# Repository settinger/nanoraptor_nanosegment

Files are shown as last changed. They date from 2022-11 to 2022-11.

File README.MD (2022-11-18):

# The NanoRaptor NanoSegment

## Experiments in miniature 7-segment displays

### Sam Ettinger, November 2022

Like many good projects, this started with [a prank tweet:](https://twitter.com/NanoRaptor/status/1483962337334022145)

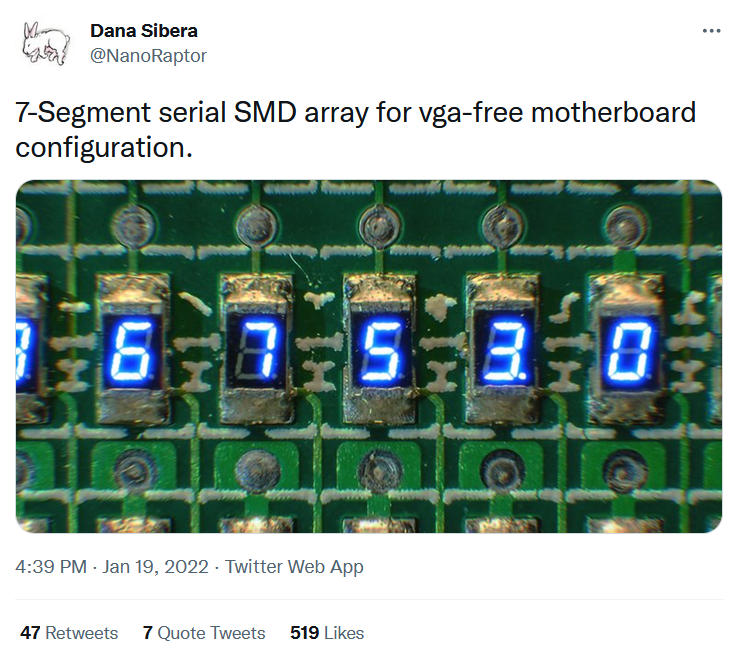
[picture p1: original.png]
A screenshot of a tweet showing surface mount resistors that have been photoshopped to look like they have 7-segment displays on them. The tweet text says "7-Segment serial SMD array for vga-free motherboard configuration."


Like many others, I immediately got sucked into hypotheticals, wondering what it would take to make one of these IRL. Some 0201-sized LEDs in a 7-segment arrangement could fit in an 0805-ish footprint, right?

There are three KiCad projects in the `kicad/` folder:
- `6pin_7seg_0806`, the first version. It's just a panelized PCB with no schematic and some, shall we say, unique features (TODO: explain)
- `6pin_7seg_0806_display_board`. Once the 6-pin 0806 modules are assembled, the modules can be soldered to this board and controlled with an ATtiny84. There are some unused 0805 footprints nearby the modules, which I thought would contribute to it looking like a "real" component.
- `nanoraptor_nanosegment`, my current idea. I want to see if I can fold up an OSH Park flex PCB into a 1208-size footprint with just two pins, like in the original tweet.

TODO: finish this

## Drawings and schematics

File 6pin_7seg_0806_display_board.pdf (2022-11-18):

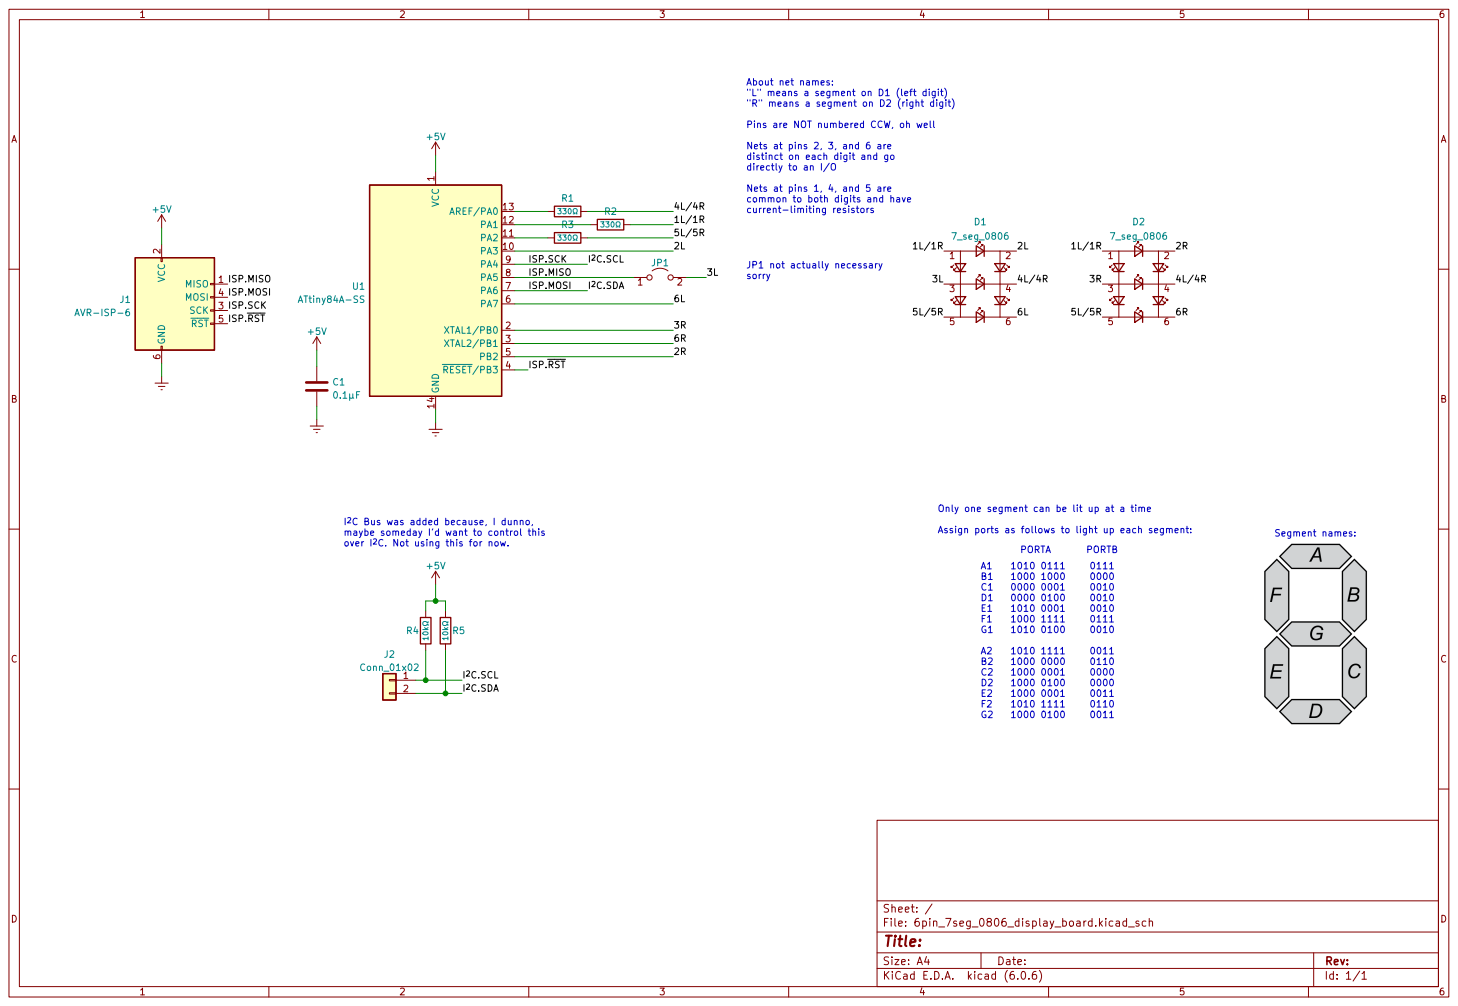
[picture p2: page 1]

About net names: "L" means a segment on D1 (left digit)

"R" means a segment on D2 (right digit) Pins are NOT numbered CCW, oh well Nets at pins 2, 3, and 6 are

distinct on each digit and go
directly to an I/O

1 PA3 10 PA2 11 PA1 12 AREF/PA0 13 GND 14 XTAL1/PB0 2 XTAL2/PB1 3 ~{RESET}/PB3 4 PB2 5 PA7 6 PA6 7 PA5 8 PA4 9 U1 ATtiny84A-SS

Nets at pins 1, 4, and 5 are
common to both digits and have

2 SCK 3 MOSI 4 ~{RST} 5 GND

0011 A1B1C1 D1E1F1G1 A2B2C2 D2E2F2G2 Only one segment can be lit up at a time

I^{2}C Bus was added because, I dunno,
maybe someday I'd want to control this
over I^{2}C. Not using this for now.

Assign ports as follows to light up each segment:

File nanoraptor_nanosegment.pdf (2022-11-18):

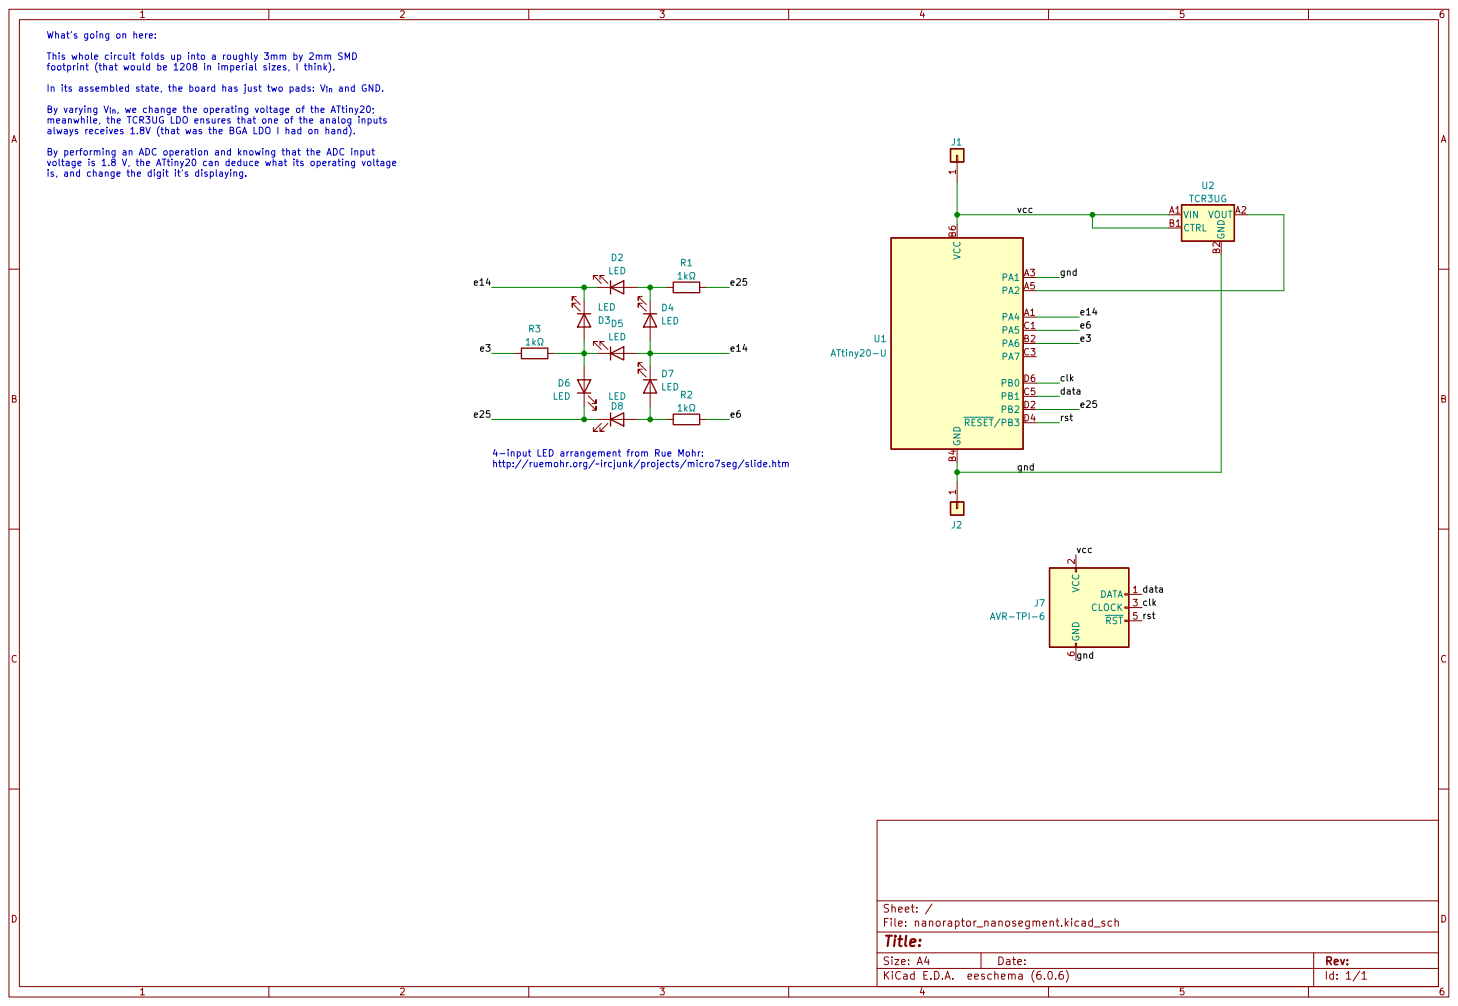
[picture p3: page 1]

This whole circuit folds up into a roughly 3mm by 2mm SMD
footprint (that would be 1208 in imperial sizes, I think).

In its assembled state, the board has just two pads: V_{in} and GND.

By varying V_{in}, we change the operating voltage of the ATtiny20;
meanwhile, the TCR3UG LDO ensures that one of the analog inputs
always receives 1.8V (that was the BGA LDO I had on hand).

By performing an ADC operation and knowing that the ADC input
voltage is 1.8 V, the ATtiny20 can deduce what its operating voltage
is, and change the digit it's displaying.

4-input LED arrangement from Rue Mohr:
http://ruemohr.org/~ircjunk/projects/micro7seg/slide.htm

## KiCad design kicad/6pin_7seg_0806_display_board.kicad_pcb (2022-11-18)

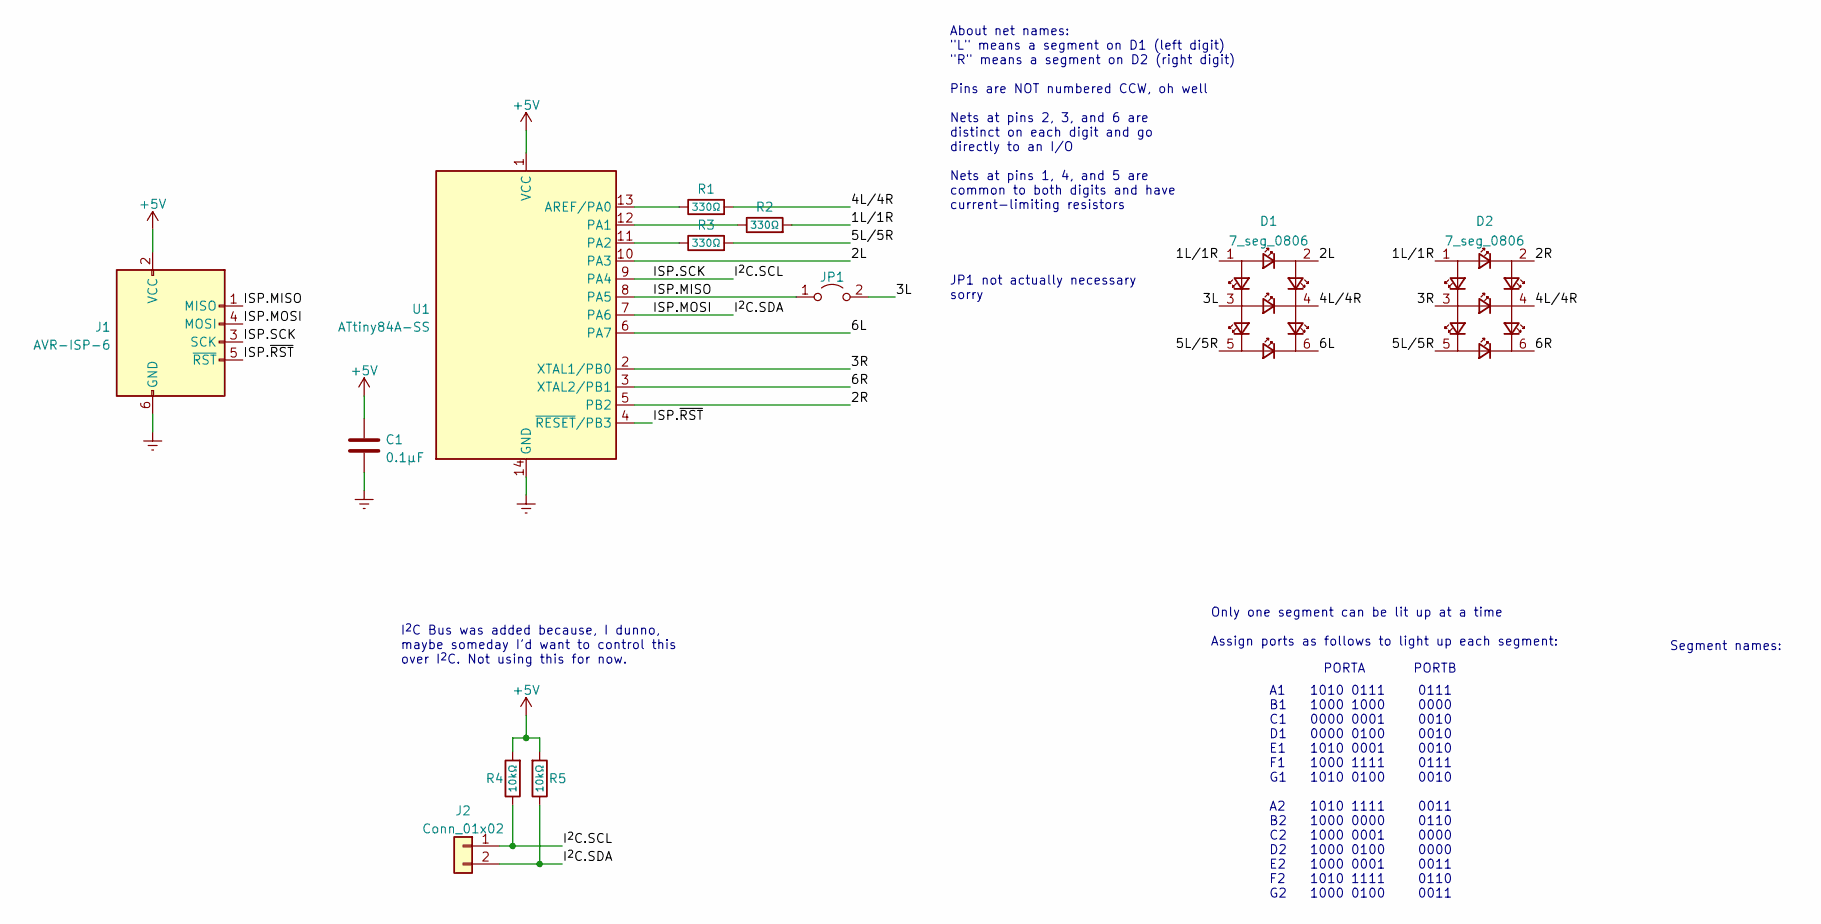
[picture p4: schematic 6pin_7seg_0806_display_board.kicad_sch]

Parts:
C1: 0.1μF; C_0805_2012Metric
D1, D2: 7_seg_0806; 7seg_land_pattern
J1: AVR-ISP-6; IDC_header_2x03_P2.54mm_edge-mount
J2: Conn_01x02; PinSocket_1x02_P2.54mm_Vertical
JP1: Jumper_2_Open; SolderJumper-2_P1.3mm_Open_RoundedPad1.0x1.5mm
R1, R2, R3: 330Ω; R_0805_2012Metric
R4, R5: 10kΩ; R_0805_2012Metric
U1: ATtiny84A-SS; SOIC-14_3.9x8.7mm_P1.27mm

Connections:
+5V: C1.1, J1.2 (VCC), R4.2, R5.2, U1.1 (VCC)
/1L/1R: D1.1 (A+F+), D2.1 (A+F+), R2.2
/2L: D1.2 (A-B+), U1.10 (PA3)
/2R: D2.2 (A-B+), U1.5 (PB2)
/3L: D1.3 (E+F-G+), JP1.2 (B)
/3R: D2.3 (E+F-G+), U1.2 (XTAL1/PB0)
/4L/4R: D1.4 (B-C+G-), D2.4 (B-C+G-), R1.2
/5L/5R: D1.5 (D+E-), D2.5 (D+E-), R3.2
/6L: D1.6 (C-D-), U1.6 (PA7)
/6R: D2.6 (C-D-), U1.3 (XTAL2/PB1)
/ISP.MISO: J1.1 (MISO), JP1.1 (A), U1.8 (PA5)
/ISP.MOSI: J1.4 (MOSI), J2.2, R5.1, U1.7 (PA6)
/ISP.SCK: J1.3 (SCK), J2.1, R4.1, U1.9 (PA4)
/ISP.~RST: J1.5 (~RST), U1.4 (~RESET/PB3)
GNDREF: C1.2, J1.6 (GND), U1.14 (GND)
unnamed: R1.1, U1.13 (AREF/PA0)
unnamed: R2.1, U1.12 (PA1)
unnamed: R3.1, U1.11 (PA2)

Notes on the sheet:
1010 0111 1000 1000 0000 0001 0000 0100 1010 0001 1000 1111 1010 0100 1010 1111 1000 0000 1000 0001 1000 0100 1000 0001 1010 1111 1000 0100
JP1 not actually necessary sorry
About net names: "L" means a segment on D1 (left digit) "R" means a segment on D2 (right digit) Pins are NOT numbered CCW, oh well Nets at pins 2, 3, and 6 are distinct on each digit and go directly to an I/O Nets at pins 1, 4, and 5 are common to both digits and have current-limiting resistors
A1 B1 C1 D1 E1 F1 G1 A2 B2 C2 D2 E2 F2 G2
0111 0000 0010 0010 0010 0111 0010 0011 0110 0000 0000 0011 0110 0011
I^{2}C Bus was added because, I dunno, maybe someday I'd want to control this over I^{2}C. Not using this for now.
Only one segment can be lit up at a time Assign ports as follows to light up each segment:
Segment names:
PORTA PORTB

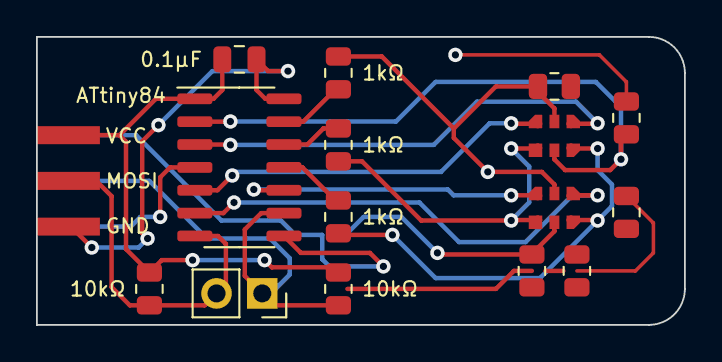
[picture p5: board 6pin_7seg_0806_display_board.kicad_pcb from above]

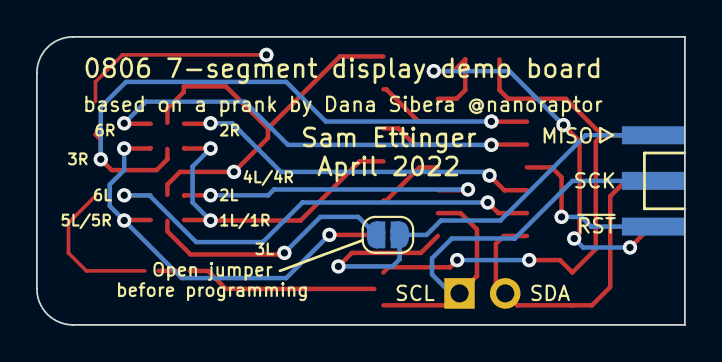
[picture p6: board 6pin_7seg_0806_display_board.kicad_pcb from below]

Board: 2 copper layers, 36.0 x 16.0 mm, 12 parts (2 on the bottom side), 18 nets.

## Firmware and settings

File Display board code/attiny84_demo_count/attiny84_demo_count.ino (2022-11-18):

// ATtiny84 setup for driving those tiny 7-segment surface mount dinguses
// THIS IS NOT GOOD CODE I WAS HUNGOVER AND DOING THIS IN THE MIDDLE OF A CON

#define PIN_1L  1  // Pin 1 of module L is connected to PA1 of the ATtiny84 (denoted "1" in ATtinyCore)
#define PIN_1R PIN_1L
#define PIN_2L  3  // Pin 2 module L: PA3 (attinycore 3)
#define PIN_2R  8  // Pin 2 module R: PB2 (attinycore 8)
#define PIN_3L  5  // Pin 3 module L: PA5 (attinycore 5)
#define PIN_3R 10  // Pin 3 module R: PB0 (attinycore 10)
#define PIN_4L  0  // Pin 4 module L: PA0 (attinycore 0)
#define PIN_4R PIN_4L
#define PIN_5L  2  // Pin 5 module L: PA2 (attinycore 2)
#define PIN_5R PIN_5L
#define PIN_6L  7  // Pin 6 module L: PA7 (attinycore 7)
#define PIN_6R  9  // Pin 6 module R: PB1 (attinycore 9)

#define PORTA_OUTPUT_MASK 0b10101111
#define PORTB_OUTPUT_MASK 0b00000111

#define OFF 0b00000000

// Arrangement of PORTA and PORTB inputs to illuminate the left module's segments, one at a time
#define SEG_A_L_PA 0b10100111
#define SEG_B_L_PA 0b10001000
#define SEG_C_L_PA 0b00000001
#define SEG_D_L_PA 0b00000100
#define SEG_E_L_PA 0b10100001
#define SEG_F_L_PA 0b10001111
#define SEG_G_L_PA 0b10100100

#define SEG_A_L_PB 0b00000111
#define SEG_B_L_PB 0b00000010
#define SEG_C_L_PB 0b00000010
#define SEG_D_L_PB 0b00000010
#define SEG_E_L_PB 0b00000010
#define SEG_F_L_PB 0b00000111
#define SEG_G_L_PB 0b00000010

// Arrangement of PORTA and PORTB inputs to illuminate the right module's segments, one at a time
#define SEG_A_R_PA 0b10101111
#define SEG_B_R_PA 0b10000000
#define SEG_C_R_PA 0b10000001
#define SEG_D_R_PA 0b10000100
#define SEG_E_R_PA 0b10000001
#define SEG_F_R_PA 0b10101111
#define SEG_G_R_PA 0b10000100

#define SEG_A_R_PB 0b00000011
#define SEG_B_R_PB 0b00000110
#define SEG_C_R_PB 0b00000000
#define SEG_D_R_PB 0b00000000
#define SEG_E_R_PB 0b00000011
#define SEG_F_R_PB 0b00000110
#define SEG_G_R_PB 0b00000011

// Some way of defining each segment and a whole character display
#define XA 0b00000001   // Segment A
#define XB 0b00000010   // Segment B (etc...)
#define XC 0b00000100
#define XD 0b00001000
#define XE 0b00010000
#define XF 0b00100000
#define XG 0b01000000

#define CHAR_0 XA | XB | XC | XD | XE | XF
#define CHAR_1 XB | XC
#define CHAR_2 XA | XB | XG | XE | XD
#define CHAR_3 XA | XB | XG | XC | XD
#define CHAR_4 XF | XG | XB | XC
#define CHAR_5 XA | XF | XG | XC | XD
#define CHAR_6 XA | XF | XE | XD | XC | XG
#define CHAR_7 XA | XB | XC
#define CHAR_8 XA | XB | XC | XD | XE | XF | XG
#define CHAR_9 XG | XF | XA | XB | XC | XD
#define CHAR_A XE | XF | XA | XB | XC | XG
#define CHAR_b XF | XE | XD | XC | XG
#define CHAR_C XA | XF | XE | XD
#define CHAR_d XB | XC | XD | XE | XG
#define CHAR_E XA | XF | XG | XE | XD
#define CHAR_F XA | XF | XG | XE
#define CHAR_NONE 0

char chars[16] = { CHAR_0, CHAR_1, CHAR_2, CHAR_3, CHAR_4, CHAR_5, CHAR_6, CHAR_7, CHAR_8, CHAR_9, CHAR_A, CHAR_b, CHAR_C, CHAR_d, CHAR_E, CHAR_F };

char currChar;             // Which character we want to display: 0 1 2 3 4 5 6 7 8 9 A b C d E F xa xb xc xd xe xf xg
int idleTime = 60;         // how many milliseconds between character updates
int segCounter = 0;        // Which segment should be illuminated (0-13)
int fooCounter = 0;
unsigned long timer1 = 0;  // Counter that tracks how much time has elapsed since the last segment was written
unsigned long timer1_init = 0;
unsigned long timer2 = 0;  // Counter that tracks how much time has elapsed since the last character was chosen
unsigned long timer2_init = 0;


void setup() {
  DDRA = PORTA_OUTPUT_MASK;   // Set A0, 1, 2, 3, 5, 7 as outputs
  DDRB = PORTB_OUTPUT_MASK;   // Set B0, 1, 2 as outputs

  PORTA = OFF;                // Set all outputs low initially
  PORTB = OFF;                // Set all outputs low initially
  
  delay(idleTime);
  
  // Loop through every segment once
  PORTA = SEG_A_L_PA;
  PORTB = SEG_A_L_PB;
  delay(idleTime);
  PORTA = SEG_B_L_PA;
  PORTB = SEG_B_L_PB;
  delay(idleTime);
  PORTA = SEG_C_L_PA;
  PORTB = SEG_C_L_PB;
  delay(idleTime);
  PORTA = SEG_D_L_PA;
  PORTB = SEG_D_L_PB;
  delay(idleTime);
  PORTA = SEG_E_L_PA;
  PORTB = SEG_E_L_PB;
  delay(idleTime);
  PORTA = SEG_F_L_PA;
  PORTB = SEG_F_L_PB;
  delay(idleTime);
  PORTA = SEG_G_L_PA;
  PORTB = SEG_G_L_PB;
  delay(idleTime);

  timer1_init = millis();
  timer2_init = millis();
}

void show0(int segCounter) {
  if (segCounter == 1) {
    PORTA = SEG_A_L_PA;
    PORTB = SEG_A_L_PB;
  } else if (segCounter == 2) {
    PORTA = SEG_B_L_PA;
    PORTB = SEG_B_L_PB;
  } else if (segCounter == 3) {
    PORTA = SEG_C_L_PA;
    PORTB = SEG_C_L_PB;
  } else if (segCounter == 4) {
    PORTA = SEG_D_L_PA;
    PORTB = SEG_D_L_PB;
  } else if (segCounter == 5) {
    PORTA = SEG_E_L_PA;
    PORTB = SEG_E_L_PB;
  } else if (segCounter == 6) {
    PORTA = SEG_F_L_PA;
    PORTB = SEG_F_L_PB;
  } else {
    PORTA = OFF;
    PORTB = OFF;
  }
}

void show1(int segCounter) {
  if (segCounter == 1) {
    PORTA = SEG_B_L_PA;
    PORTB = SEG_B_L_PB;
  } else if (segCounter == 2) {
    PORTA = SEG_C_L_PA;
    PORTB = SEG_C_L_PB;
  } else {
    PORTA = OFF;
    PORTB = OFF;
  }
}

void show2(int segCounter) {
  if (segCounter == 1) {
    PORTA = SEG_A_L_PA;
    PORTB = SEG_A_L_PB;
  } else if (segCounter == 2) {
    PORTA = SEG_B_L_PA;
    PORTB = SEG_B_L_PB;
  } else if (segCounter == 3) {
    PORTA = SEG_G_L_PA;
    PORTB = SEG_G_L_PB;
  } else if (segCounter == 4) {
    PORTA = SEG_E_L_PA;
    PORTB = SEG_E_L_PB;
  } else if (segCounter == 5) {
    PORTA = SEG_D_L_PA;
    PORTB = SEG_D_L_PB;
  } else {
    PORTA = OFF;
    PORTB = OFF;
  }
}

void show3(int segCounter) {
  if (segCounter == 1) {
    PORTA = SEG_A_L_PA;
    PORTB = SEG_A_L_PB;
  } else if (segCounter == 2) {
    PORTA = SEG_B_L_PA;
    PORTB = SEG_B_L_PB;
  } else if (segCounter == 3) {
    PORTA = SEG_G_L_PA;
    PORTB = SEG_G_L_PB;
  } else if (segCounter == 4) {
    PORTA = SEG_C_L_PA;
    PORTB = SEG_C_L_PB;
  } else if (segCounter == 5) {
    PORTA = SEG_D_L_PA;
    PORTB = SEG_D_L_PB;
  } else {
    PORTA = OFF;
    PORTB = OFF;
  }
}

void show4(int segCounter) {
if (segCounter == 2) {
    PORTA = SEG_B_L_PA;
    PORTB = SEG_B_L_PB;
  } else if (segCounter == 3) {
    PORTA = SEG_C_L_PA;
    PORTB = SEG_C_L_PB;
  } else if (segCounter == 6) {
    PORTA = SEG_F_L_PA;
    PORTB = SEG_F_L_PB;
  } else if (segCounter == 7) {
    PORTA = SEG_G_L_PA;
    PORTB = SEG_G_L_PB;
  } else {
    PORTA = OFF;
    PORTB = OFF;
  }
}

void show5(int segCounter) {
  if (segCounter == 1) {
    PORTA = SEG_A_L_PA;
    PORTB = SEG_A_L_PB;
  } else if (segCounter == 3) {
    PORTA = SEG_C_L_PA;
    PORTB = SEG_C_L_PB;
  } else if (segCounter == 4) {
    PORTA = SEG_D_L_PA;
    PORTB = SEG_D_L_PB;
  } else if (segCounter == 6) {
    PORTA = SEG_F_L_PA;
    PORTB = SEG_F_L_PB;
  } else if (segCounter == 7) {
    PORTA = SEG_G_L_PA;
    PORTB = SEG_G_L_PB;
  } else {
    PORTA = OFF;
    PORTB = OFF;
  }
}

void show6(int segCounter) {
  if (segCounter == 1) {
    PORTA = SEG_A_L_PA;
    PORTB = SEG_A_L_PB;
  } else if (segCounter == 3) {
    PORTA = SEG_C_L_PA;
    PORTB = SEG_C_L_PB;
  } else if (segCounter == 4) {
    PORTA = SEG_D_L_PA;
    PORTB = SEG_D_L_PB;
  } else if (segCounter == 5) {
    PORTA = SEG_E_L_PA;
    PORTB = SEG_E_L_PB;
  } else if (segCounter == 6) {
    PORTA = SEG_F_L_PA;
    PORTB = SEG_F_L_PB;
  } else if (segCounter == 7) {
    PORTA = SEG_G_L_PA;
    PORTB = SEG_G_L_PB;
  } else {
    PORTA = OFF;
    PORTB = OFF;
  }
}

void show7(int segCounter) {
  if (segCounter == 1) {
    PORTA = SEG_A_L_PA;
    PORTB = SEG_A_L_PB;
  } else if (segCounter == 3) {
    PORTA = SEG_B_L_PA;
    PORTB = SEG_B_L_PB;
  } else if (segCounter == 5) {
    PORTA = SEG_C_L_PA;
    PORTB = SEG_C_L_PB;
  } else {
    PORTA = OFF;
    PORTB = OFF;
  }
}

void show8(int segCounter) {
  if (segCounter == 1) {
    PORTA = SEG_A_L_PA;
    PORTB = SEG_A_L_PB;
  } else if (segCounter == 2) {
    PORTA = SEG_B_L_PA;
    PORTB = SEG_B_L_PB;
  } else if (segCounter == 3) {
    PORTA = SEG_C_L_PA;
    PORTB = SEG_C_L_PB;
  } else if (segCounter == 4) {
    PORTA = SEG_D_L_PA;
    PORTB = SEG_D_L_PB;
  } else if (segCounter == 5) {
    PORTA = SEG_E_L_PA;
    PORTB = SEG_E_L_PB;
  } else if (segCounter == 6) {
    PORTA = SEG_F_L_PA;
    PORTB = SEG_F_L_PB;
  } else if (segCounter == 7) {
    PORTA = SEG_G_L_PA;
    PORTB = SEG_G_L_PB;
  } else {
    PORTA = OFF;
    PORTB = OFF;
  }
}

void show9(int segCounter) {
  if (segCounter == 1) {
    PORTA = SEG_A_L_PA;
    PORTB = SEG_A_L_PB;
  } else if (segCounter == 2) {
    PORTA = SEG_B_L_PA;
    PORTB = SEG_B_L_PB;
  } else if (segCounter == 3) {
    PORTA = SEG_C_L_PA;
    PORTB = SEG_C_L_PB;
  } else if (segCounter == 4) {
    PORTA = SEG_D_L_PA;
    PORTB = SEG_D_L_PB;
  } else if (segCounter == 6) {
    PORTA = SEG_F_L_PA;
    PORTB = SEG_F_L_PB;
  } else if (segCounter == 7) {
    PORTA = SEG_G_L_PA;
    PORTB = SEG_G_L_PB;
  } else {
    PORTA = OFF;
    PORTB = OFF;
  }
}


void showA(int segCounter) {
  if (segCounter == 1) {
    PORTA = SEG_A_L_PA;
    PORTB = SEG_A_L_PB;
  } else if (segCounter == 2) {
    PORTA = SEG_B_L_PA;
    PORTB = SEG_B_L_PB;
  } else if (segCounter == 3) {
    PORTA = SEG_C_L_PA;
    PORTB = SEG_C_L_PB;
  } else if (segCounter == 5) {
    PORTA = SEG_E_L_PA;
    PORTB = SEG_E_L_PB;
  } else if (segCounter == 6) {
    PORTA = SEG_F_L_PA;
    PORTB = SEG_F_L_PB;
  } else if (segCounter == 7) {
    PORTA = SEG_G_L_PA;
    PORTB = SEG_G_L_PB;
  } else {
    PORTA = OFF;
    PORTB = OFF;
  }
}

void loop() {
  segCounter++;
  if (segCounter > 8) {
    segCounter = 0;
    fooCounter++;
  }
  if (fooCounter < 1200) {
    show0(segCounter);
  } else if (fooCounter < 2400) {
    show1(segCounter);
  } else if (fooCounter < 3600) {
    show2(segCounter);
  } else if (fooCounter < 4800) {
    show3(segCounter);
  } else if (fooCounter < 6000) {
    show4(segCounter);
  } else if (fooCounter < 7200) {
    show5(segCounter);
  } else if (fooCounter < 8400) {
    show6(segCounter);
  } else if (fooCounter < 9600) {
    show7(segCounter);
  } else if (fooCounter < 10800) {
    show8(segCounter);
  } else if (fooCounter < 12000) {
    show9(segCounter);
  } else if (fooCounter < 13200) {
    showA(segCounter);
  } else {
    fooCounter = 0;
  }
  delayMicroseconds(50);
}

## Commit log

2022-11-18 Init commit
    [6pin_7seg_0806.kicad_pcb, 6pin_7seg_0806.kicad_sch, 6pin_7seg_0806_display_board.kicad_pcb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]
2022-11-18 attiny84 arduino sketch
